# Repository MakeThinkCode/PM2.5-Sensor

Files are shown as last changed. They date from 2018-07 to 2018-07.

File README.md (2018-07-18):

# sensingtheenvpm25

Note for the web site:  the purpose of "sqlconnect-example.php" is to maintain privacy of the database access credentials; it should be copied to the web server, renamed to "sqlconnect.php", and then edited to contain the actual username etc.  The resulting sqlconnect.php should NOT then be included in the github source.

to do: docs, e.g. process for wiring, materials list (e.g. acrylic), process for editing the sensor code (setting the machine name), goals for installation, process for getting from the Fusion360 file to an assembled shelter, process for uploading data to the web site, calibration, setting up the web server (database, password file), next steps list, and so on.

Process for cutting the shelter from the 20180521 drawing:
1. Requires (from Home Depot, for instance) 3 sheets of 11x14 .093" thick acrylic per shelter.  (aside: The shelter design has slot widths designed for that thickness; you could change the "t" (thickness) parameter of the .f3d drawing and recompute and it SHOULD work, but no guarantees -- I've had problems adjusting .f3d parameters in the past.)
2. From the .f3d file, make a drawing (select visible components, D size sheet l:1 scale) of the parts, deleting the legend and border, precise layout not critical.
3.  Export the drawing into a PDF, since that's what Adobe Illustrator can read
4.  In Illustrator, change the line weight to .001pt and the line colors to red; also, right-click on the unwanted rectangular border, choose "release clipping mask", and then delete the border.
5.  In Illustrator, make 3 new drawings, 11x14, and distribute copies of the (eight) shelter components among the 3 drawings.  I ended up needing to make two changes to settings in the print dialog:  placement in the upper left corner and no auto-rotate.
6.  From Illustrator, do the laser cutting (print to the Trotec, and follow the normal instructions; I used 90% power and 0.70 speed with Auto PPI).

Assembling the shelter:
First, attach the Arduino and the Plantower to the centerboard with twist-ties through the holes.  Then slot together the outside and base of the shelter and drop in the centerboard with the sensor.  Put the lid in place and use two more twist-ties through the small top holes to hold the lid down, which is the step which latches everything together firmly.  Finally, slide the door into place.

Process for loading code onto the sensor:
Upload the code using the Arduino IDE.  One edit will be necessary for each sensor:  set the SENSOR_NAME in the code around line 40 (of code version 15, which is current as of July 2018). The name is included in the sensor output file and used for tagging the data in the database.  The name is also used in generating the file name for the sensor's data files (a new datafile is created every time the sensor is started:  a sensor named PARK will have data files named PARK_001.csv, PARK_002.csv, etc).  The second edit to remember is that any time the sensor code is modified, the SOFTWARE_VERSION should be changed; this will help separate out any data handling changes which need to be made in the server code and may be required for correct analysis of the data.
(need note here about setting up Arduino IDE, installing the Teensy loader, setting the "Port" to connect, using the console to check that the sensor is running properly, etc.)

Process for uploading data to the database, as of 7/2018:
1. Unplug the sensor from its power source.
2. Remove the micro-SD card from the Arduino.  On the micro-SD card will be files with names like PARK_001.csv, one for each time the sensor has been powered up.  You'll need to upload (one by one) any of these which haven't already been uploaded; you may want to copy them to your local computer for convenience.
3. Navigate a web browser to http://spatialreasoning.com/particulates and choose "Upload".
4.  On the upload page, first "browse" to find the .csv file from the sensor's micro-SD card, then "Upload PM2.5 Data" to actually do the upload.  This will take at least several seconds, with no immediate visual feedback; please be patient.
5.  When the upload finishes, the web page will display a graph of the readings, and will be ready to upload another file if you have multiple to upload.
6.  You likely will want to remove the .csv files from the micro-SD card to avoid future confusion about whether the files have been uploaded already.  If you do so, the next time the sensor is started up it will restart the data file numbering from 001.
7.  Replace the micro-SD card in the sensor.
8.  Plug the sensor in again.

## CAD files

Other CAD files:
shelter/lasercutting20180521/shelter20180521a v0.f3d
shelter/shelter2018-03.f3d

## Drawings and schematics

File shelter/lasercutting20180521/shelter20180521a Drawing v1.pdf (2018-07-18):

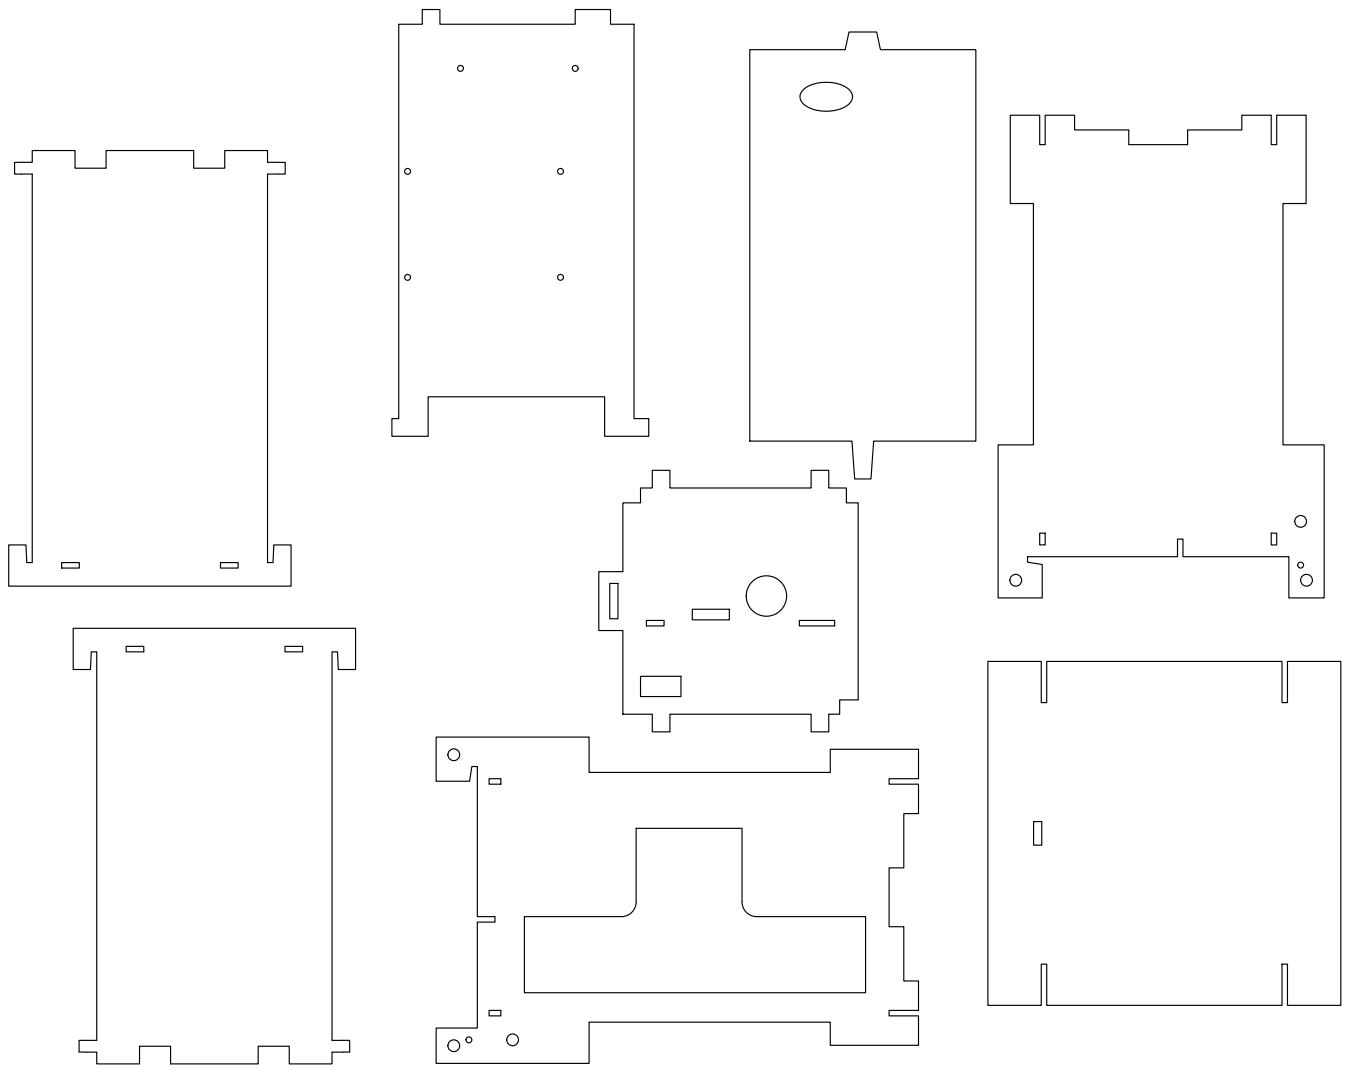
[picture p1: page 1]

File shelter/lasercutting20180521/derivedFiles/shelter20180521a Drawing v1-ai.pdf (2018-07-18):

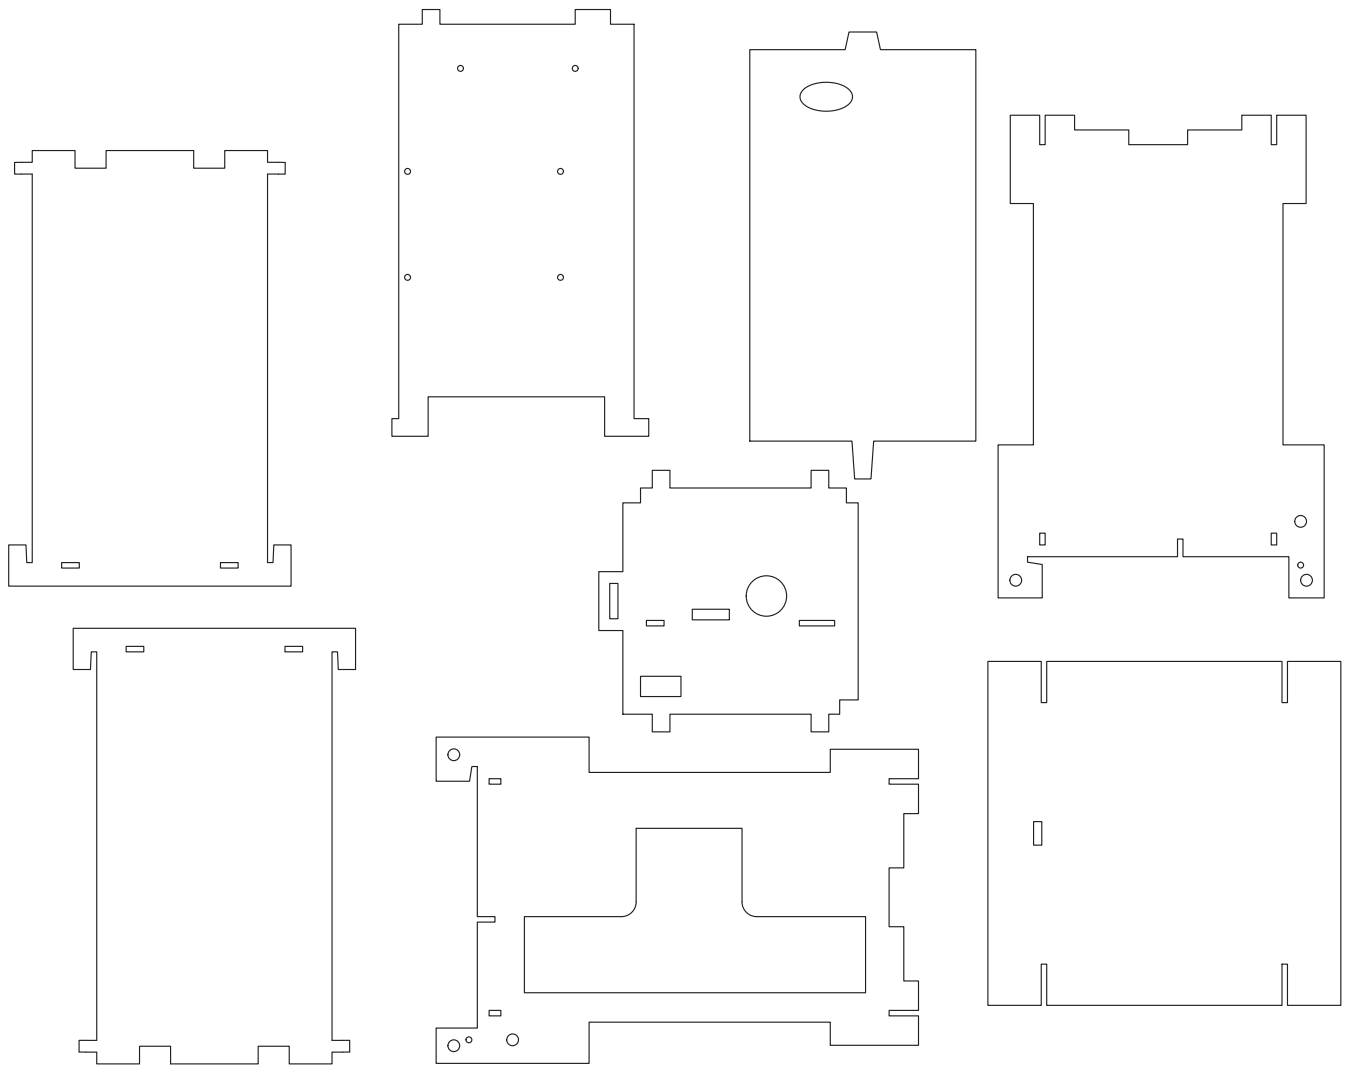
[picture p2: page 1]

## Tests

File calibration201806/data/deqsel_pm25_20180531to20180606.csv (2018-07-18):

PM2.5 Est[ug/m3(L)] Station: Portland SE Lafayette Periodically: 5/31/2018 12:05 AM-6/8/2018 12:00 AM Type: AVG 5 Mins. [5 Mins.]
Date & Time | PM2.5 Est
 | ug/m3(L)
5/31/2018 12:05 AM | 2.4
5/31/2018 12:10 AM | 2.2
5/31/2018 12:15 AM | 2.1
5/31/2018 12:20 AM | 2.1
5/31/2018 12:25 AM | 2.1
5/31/2018 12:30 AM | 2.0
5/31/2018 12:35 AM | 2.0
5/31/2018 12:40 AM | 2.0
5/31/2018 12:45 AM | 2.0
5/31/2018 12:50 AM | 2.0
5/31/2018 12:55 AM | 2.0
5/31/2018 1:00 AM | 2.0
5/31/2018 1:05 AM | 2.1
5/31/2018 1:10 AM | 2.1
5/31/2018 1:15 AM | 2.0
5/31/2018 1:20 AM | 2.0
5/31/2018 1:25 AM | 2.2
5/31/2018 1:30 AM | 2.1
5/31/2018 1:35 AM | 1.9
5/31/2018 1:40 AM | 2.1
5/31/2018 1:45 AM | 1.9
5/31/2018 1:50 AM | 2.0
5/31/2018 1:55 AM | 1.9
5/31/2018 2:00 AM | 1.8
5/31/2018 2:05 AM | 1.8
5/31/2018 2:10 AM | 1.9
5/31/2018 2:15 AM | 1.9
5/31/2018 2:20 AM | 1.9
5/31/2018 2:25 AM | 2.0
5/31/2018 2:30 AM | 2.0
5/31/2018 2:35 AM | 1.9
5/31/2018 2:40 AM | 1.9
5/31/2018 2:45 AM | 2.1
5/31/2018 2:50 AM | 2.1
5/31/2018 2:55 AM | 2.0
5/31/2018 3:00 AM | 2.0
5/31/2018 3:05 AM | 2.1
5/31/2018 3:10 AM | 2.3
5/31/2018 3:15 AM | 2.2
5/31/2018 3:20 AM | 2.2
5/31/2018 3:25 AM | 2.1
5/31/2018 3:30 AM | 2.2
5/31/2018 3:35 AM | 2.2
5/31/2018 3:40 AM | 2.3
5/31/2018 3:45 AM | 2.2
5/31/2018 3:50 AM | 2.2
5/31/2018 3:55 AM | 2.3
5/31/2018 4:00 AM | 2.5
5/31/2018 4:05 AM | 2.5
5/31/2018 4:10 AM | 2.8
5/31/2018 4:15 AM | 2.8
5/31/2018 4:20 AM | 2.9
5/31/2018 4:25 AM | 2.9
5/31/2018 4:30 AM | 2.8
5/31/2018 4:35 AM | 2.6
5/31/2018 4:40 AM | 2.7
5/31/2018 4:45 AM | 2.6
5/31/2018 4:50 AM | 2.1
5/31/2018 4:55 AM | 2.1
5/31/2018 5:00 AM | 2.1
5/31/2018 5:05 AM | 2.1
5/31/2018 5:10 AM | 2.3
5/31/2018 5:15 AM | 2.4
5/31/2018 5:20 AM | 2.7
5/31/2018 5:25 AM | 2.6
5/31/2018 5:30 AM | 2.6
5/31/2018 5:35 AM | 2.4
5/31/2018 5:40 AM | 2.3
5/31/2018 5:45 AM | 2.2
5/31/2018 5:50 AM | 2.1
5/31/2018 5:55 AM | zero
5/31/2018 6:00 AM | Calib
5/31/2018 6:05 AM | Purge
5/31/2018 6:10 AM | Purge
5/31/2018 6:15 AM | DL/Computer issue
5/31/2018 6:20 AM | 2.3
5/31/2018 6:25 AM | 2.4
5/31/2018 6:30 AM | 2.4
5/31/2018 6:35 AM | 2.4
5/31/2018 6:40 AM | 2.3
5/31/2018 6:45 AM | 2.3
5/31/2018 6:50 AM | 2.2
5/31/2018 6:55 AM | 2.5
5/31/2018 7:00 AM | 2.5
5/31/2018 7:05 AM | 2.7
5/31/2018 7:10 AM | 2.6
5/31/2018 7:15 AM | 2.4
5/31/2018 7:20 AM | 2.2
5/31/2018 7:25 AM | 2.2
5/31/2018 7:30 AM | 2.2
5/31/2018 7:35 AM | 2.3
5/31/2018 7:40 AM | 2.5
5/31/2018 7:45 AM | 2.4
5/31/2018 7:50 AM | 2.3
5/31/2018 7:55 AM | 2.2
5/31/2018 8:00 AM | 2.3
5/31/2018 8:05 AM | 2.4
5/31/2018 8:10 AM | 2.5
5/31/2018 8:15 AM | 2.6
5/31/2018 8:20 AM | 2.4
5/31/2018 8:25 AM | 2.6
5/31/2018 8:30 AM | 2.4
5/31/2018 8:35 AM | 2.7
5/31/2018 8:40 AM | 2.7
5/31/2018 8:45 AM | 2.7
5/31/2018 8:50 AM | 2.7
5/31/2018 8:55 AM | 2.6
5/31/2018 9:00 AM | 2.5
5/31/2018 9:05 AM | 2.3
5/31/2018 9:10 AM | 2.3
5/31/2018 9:15 AM | 2.2
5/31/2018 9:20 AM | 2.2
5/31/2018 9:25 AM | 2.1
5/31/2018 9:30 AM | 2.3
5/31/2018 9:35 AM | 2.3
5/31/2018 9:40 AM | 2.2
5/31/2018 9:45 AM | 2.1
5/31/2018 9:50 AM | 2.1
5/31/2018 9:55 AM | 2.1
5/31/2018 10:00 AM | 2.2
5/31/2018 10:05 AM | 2.2
5/31/2018 10:10 AM | 2.0
5/31/2018 10:15 AM | 1.8
5/31/2018 10:20 AM | 2.0
5/31/2018 10:25 AM | 1.8
5/31/2018 10:30 AM | 1.8
5/31/2018 10:35 AM | 1.9
5/31/2018 10:40 AM | 1.9
5/31/2018 10:45 AM | 1.7
5/31/2018 10:50 AM | 1.9
5/31/2018 10:55 AM | 2.0
5/31/2018 11:00 AM | 1.9
5/31/2018 11:05 AM | 2.0
5/31/2018 11:10 AM | 2.0
5/31/2018 11:15 AM | 1.8
5/31/2018 11:20 AM | 2.0
5/31/2018 11:25 AM | 2.0
5/31/2018 11:30 AM | 1.9
5/31/2018 11:35 AM | 1.9
5/31/2018 11:40 AM | 1.9
5/31/2018 11:45 AM | 1.9
5/31/2018 11:50 AM | 2.0
5/31/2018 11:55 AM | 2.1
5/31/2018 12:00 PM | 2.4
5/31/2018 12:05 PM | 2.2
5/31/2018 12:10 PM | 2.3
5/31/2018 12:15 PM | 2.2
5/31/2018 12:20 PM | 2.3
5/31/2018 12:25 PM | 2.4
5/31/2018 12:30 PM | 2.3
5/31/2018 12:35 PM | 2.4
5/31/2018 12:40 PM | 2.6
5/31/2018 12:45 PM | 2.5
5/31/2018 12:50 PM | 2.7
5/31/2018 12:55 PM | 2.6
5/31/2018 1:00 PM | 2.8
5/31/2018 1:05 PM | 2.9
5/31/2018 1:10 PM | 3.0
5/31/2018 1:15 PM | 2.9
5/31/2018 1:20 PM | 3.0
5/31/2018 1:25 PM | 3.0
5/31/2018 1:30 PM | 2.7
5/31/2018 1:35 PM | 2.4
5/31/2018 1:40 PM | 2.7
5/31/2018 1:45 PM | 3.0
5/31/2018 1:50 PM | 3.2
5/31/2018 1:55 PM | 3.2
5/31/2018 2:00 PM | 3.2
5/31/2018 2:05 PM | 3.1
5/31/2018 2:10 PM | 3.0
5/31/2018 2:15 PM | 3.1
5/31/2018 2:20 PM | 3.0
5/31/2018 2:25 PM | 3.2
5/31/2018 2:30 PM | 3.4
5/31/2018 2:35 PM | 3.4
5/31/2018 2:40 PM | 3.6
5/31/2018 2:45 PM | 3.5
5/31/2018 2:50 PM | 3.0
5/31/2018 2:55 PM | 2.6
5/31/2018 3:00 PM | 2.8
5/31/2018 3:05 PM | 2.4
5/31/2018 3:10 PM | 2.3
5/31/2018 3:15 PM | 2.0
5/31/2018 3:20 PM | 2.1
5/31/2018 3:25 PM | 2.1
5/31/2018 3:30 PM | 2.2
5/31/2018 3:35 PM | 2.6
5/31/2018 3:40 PM | 2.7
5/31/2018 3:45 PM | 2.6
5/31/2018 3:50 PM | 2.5
5/31/2018 3:55 PM | 2.3
5/31/2018 4:00 PM | 2.3
5/31/2018 4:05 PM | 2.4
5/31/2018 4:10 PM | 3.0
5/31/2018 4:15 PM | 2.7
5/31/2018 4:20 PM | 2.9
5/31/2018 4:25 PM | 2.8
5/31/2018 4:30 PM | 2.6
5/31/2018 4:35 PM | 2.0
5/31/2018 4:40 PM | 2.2
5/31/2018 4:45 PM | 1.9
5/31/2018 4:50 PM | 1.9
5/31/2018 4:55 PM | 2.0
5/31/2018 5:00 PM | 1.8
5/31/2018 5:05 PM | 2.1
5/31/2018 5:10 PM | 2.5
5/31/2018 5:15 PM | 2.4
5/31/2018 5:20 PM | 2.5
5/31/2018 5:25 PM | 2.4
5/31/2018 5:30 PM | 2.5
5/31/2018 5:35 PM | 2.3
5/31/2018 5:40 PM | 2.5
5/31/2018 5:45 PM | 2.2
5/31/2018 5:50 PM | 2.3
5/31/2018 5:55 PM | 2.1
5/31/2018 6:00 PM | 2.3
5/31/2018 6:05 PM | 2.3
5/31/2018 6:10 PM | 2.4
5/31/2018 6:15 PM | 2.3
5/31/2018 6:20 PM | 2.2
5/31/2018 6:25 PM | 2.5
5/31/2018 6:30 PM | 2.4
5/31/2018 6:35 PM | 2.3
5/31/2018 6:40 PM | 1.8
5/31/2018 6:45 PM | 2.4
5/31/2018 6:50 PM | 3.8
5/31/2018 6:55 PM | 3.5
5/31/2018 7:00 PM | 3.1
5/31/2018 7:05 PM | 3.2
5/31/2018 7:10 PM | 3.1
5/31/2018 7:15 PM | 3.7
5/31/2018 7:20 PM | 3.6
5/31/2018 7:25 PM | 2.4
5/31/2018 7:30 PM | 2.1
5/31/2018 7:35 PM | 2.0
5/31/2018 7:40 PM | 2.3
5/31/2018 7:45 PM | 2.7
5/31/2018 7:50 PM | 2.8
5/31/2018 7:55 PM | 2.9
5/31/2018 8:00 PM | 3.0
5/31/2018 8:05 PM | 2.9
5/31/2018 8:10 PM | 2.9
5/31/2018 8:15 PM | 3.0
5/31/2018 8:20 PM | 3.1
5/31/2018 8:25 PM | 2.9
5/31/2018 8:30 PM | 2.8
5/31/2018 8:35 PM | 2.9
5/31/2018 8:40 PM | 2.9
5/31/2018 8:45 PM | 3.0
5/31/2018 8:50 PM | 3.2
5/31/2018 8:55 PM | 3.0
5/31/2018 9:00 PM | 2.8
5/31/2018 9:05 PM | 2.7
5/31/2018 9:10 PM | 2.8
5/31/2018 9:15 PM | 3.1
5/31/2018 9:20 PM | 3.1
5/31/2018 9:25 PM | 3.3
5/31/2018 9:30 PM | 3.2
5/31/2018 9:35 PM | 3.6
5/31/2018 9:40 PM | 4.0
5/31/2018 9:45 PM | 3.9
5/31/2018 9:50 PM | 4.3
5/31/2018 9:55 PM | 4.2
5/31/2018 10:00 PM | 4.1
5/31/2018 10:05 PM | 4.0
5/31/2018 10:10 PM | 4.2
5/31/2018 10:15 PM | 4.5
5/31/2018 10:20 PM | 4.9
5/31/2018 10:25 PM | 5.0
5/31/2018 10:30 PM | 5.4
5/31/2018 10:35 PM | 5.5
5/31/2018 10:40 PM | 5.0
5/31/2018 10:45 PM | 4.3
5/31/2018 10:50 PM | 3.9
5/31/2018 10:55 PM | 3.4
5/31/2018 11:00 PM | 3.6
5/31/2018 11:05 PM | 3.6
5/31/2018 11:10 PM | 3.6
5/31/2018 11:15 PM | 3.8
5/31/2018 11:20 PM | 4.0
5/31/2018 11:25 PM | 4.6
5/31/2018 11:30 PM | 5.1
5/31/2018 11:35 PM | 4.9
5/31/2018 11:40 PM | 3.9
5/31/2018 11:45 PM | 3.4
5/31/2018 11:50 PM | 3.4
5/31/2018 11:55 PM | 3.2
5/31/2018 24:00 AM | 3.0
6/1/2018 12:05 AM | 2.9
6/1/2018 12:10 AM | 3.6
6/1/2018 12:15 AM | 3.6
6/1/2018 12:20 AM | 3.4
6/1/2018 12:25 AM | 3.5
6/1/2018 12:30 AM | 3.3
6/1/2018 12:35 AM | 3.3
6/1/2018 12:40 AM | 3.4
6/1/2018 12:45 AM | 3.6
6/1/2018 12:50 AM | 4.1
6/1/2018 12:55 AM | 3.7
6/1/2018 1:00 AM | 3.6
6/1/2018 1:05 AM | 3.7
6/1/2018 1:10 AM | 3.6
6/1/2018 1:15 AM | 3.4
6/1/2018 1:20 AM | 3.6
6/1/2018 1:25 AM | 4.6
6/1/2018 1:30 AM | 4.5
6/1/2018 1:35 AM | 4.4
6/1/2018 1:40 AM | 4.1
6/1/2018 1:45 AM | 4.1
6/1/2018 1:50 AM | 4.1
6/1/2018 1:55 AM | 4.1
6/1/2018 2:00 AM | 3.8
6/1/2018 2:05 AM | 3.9
6/1/2018 2:10 AM | 3.8
6/1/2018 2:15 AM | 3.7
6/1/2018 2:20 AM | 3.8
6/1/2018 2:25 AM | 3.9
6/1/2018 2:30 AM | 4.0
6/1/2018 2:35 AM | 4.1
6/1/2018 2:40 AM | 4.0
6/1/2018 2:45 AM | 3.8
6/1/2018 2:50 AM | 3.8
6/1/2018 2:55 AM | 3.6
6/1/2018 3:00 AM | 3.4
6/1/2018 3:05 AM | 3.6
6/1/2018 3:10 AM | 3.5
6/1/2018 3:15 AM | 3.3
6/1/2018 3:20 AM | 3.1
6/1/2018 3:25 AM | 3.1
6/1/2018 3:30 AM | 3.1
6/1/2018 3:35 AM | 3.2
6/1/2018 3:40 AM | 3.1
6/1/2018 3:45 AM | 3.2
6/1/2018 3:50 AM | 3.3
6/1/2018 3:55 AM | 3.4
6/1/2018 4:00 AM | 3.2
6/1/2018 4:05 AM | 3.5
6/1/2018 4:10 AM | 3.9
6/1/2018 4:15 AM | 3.6
6/1/2018 4:20 AM | 3.9
6/1/2018 4:25 AM | 3.9
6/1/2018 4:30 AM | 3.7
6/1/2018 4:35 AM | 3.9
6/1/2018 4:40 AM | 3.7
6/1/2018 4:45 AM | 3.6
6/1/2018 4:50 AM | 3.7
6/1/2018 4:55 AM | 3.5
6/1/2018 5:00 AM | 3.4
6/1/2018 5:05 AM | 3.3
6/1/2018 5:10 AM | 3.3
6/1/2018 5:15 AM | 3.1
6/1/2018 5:20 AM | 3.1
6/1/2018 5:25 AM | 3.2
6/1/2018 5:30 AM | 3.2
6/1/2018 5:35 AM | 3.2
6/1/2018 5:40 AM | 3.3
6/1/2018 5:45 AM | 3.3
6/1/2018 5:50 AM | 3.2
6/1/2018 5:55 AM | zero
6/1/2018 6:00 AM | Calib
6/1/2018 6:05 AM | Purge
6/1/2018 6:10 AM | Purge
6/1/2018 6:15 AM | DL/Computer issue
6/1/2018 6:20 AM | 3.5
6/1/2018 6:25 AM | 3.5
6/1/2018 6:30 AM | 3.5
6/1/2018 6:35 AM | 3.7
6/1/2018 6:40 AM | 4.0
6/1/2018 6:45 AM | 3.8
6/1/2018 6:50 AM | 3.5
6/1/2018 6:55 AM | 3.4
6/1/2018 7:00 AM | 3.3
6/1/2018 7:05 AM | 3.1
6/1/2018 7:10 AM | 3.2
6/1/2018 7:15 AM | 3.0
6/1/2018 7:20 AM | 3.3
6/1/2018 7:25 AM | 4.0
6/1/2018 7:30 AM | 4.0
6/1/2018 7:35 AM | 3.9
6/1/2018 7:40 AM | 3.9
6/1/2018 7:45 AM | 3.3
6/1/2018 7:50 AM | 3.1
6/1/2018 7:55 AM | 3.1
6/1/2018 8:00 AM | 2.8
6/1/2018 8:05 AM | 2.7
6/1/2018 8:10 AM | 2.8
6/1/2018 8:15 AM | 2.5
6/1/2018 8:20 AM | 2.5
6/1/2018 8:25 AM | 2.6
6/1/2018 8:30 AM | 2.6
6/1/2018 8:35 AM | 2.5
6/1/2018 8:40 AM | 2.4
6/1/2018 8:45 AM | 2.4
6/1/2018 8:50 AM | 2.3
6/1/2018 8:55 AM | 1.9
6/1/2018 9:00 AM | 2.1
6/1/2018 9:05 AM | 1.9
6/1/2018 9:10 AM | 2.0
6/1/2018 9:15 AM | 2.0
6/1/2018 9:20 AM | 1.9
6/1/2018 9:25 AM | 2.0
6/1/2018 9:30 AM | 1.9
6/1/2018 9:35 AM | 1.9
6/1/2018 9:40 AM | 1.7
6/1/2018 9:45 AM | 1.7
6/1/2018 9:50 AM | 1.6
6/1/2018 9:55 AM | 1.7
6/1/2018 10:00 AM | 1.7
6/1/2018 10:05 AM | 1.7
6/1/2018 10:10 AM | 1.6
6/1/2018 10:15 AM | 1.7
6/1/2018 10:20 AM | 2.0
6/1/2018 10:25 AM | 2.1
6/1/2018 10:30 AM | 1.7
6/1/2018 10:35 AM | 1.5
6/1/2018 10:40 AM | 1.6
6/1/2018 10:45 AM | 1.6
6/1/2018 10:50 AM | 1.8
6/1/2018 10:55 AM | 1.8
6/1/2018 11:00 AM | 1.6
6/1/2018 11:05 AM | 1.8
6/1/2018 11:10 AM | 1.7
6/1/2018 11:15 AM | 1.7
6/1/2018 11:20 AM | 1.7
6/1/2018 11:25 AM | 1.6
6/1/2018 11:30 AM | 1.7
6/1/2018 11:35 AM | 1.8
6/1/2018 11:40 AM | 1.9
6/1/2018 11:45 AM | 2.0
6/1/2018 11:50 AM | 1.8
6/1/2018 11:55 AM | 2.0
6/1/2018 12:00 PM | 2.1
6/1/2018 12:05 PM | 2.0
6/1/2018 12:10 PM | 2.1
6/1/2018 12:15 PM | 2.1
6/1/2018 12:20 PM | 2.1
6/1/2018 12:25 PM | 2.2
6/1/2018 12:30 PM | 2.2
6/1/2018 12:35 PM | 2.2
6/1/2018 12:40 PM | 2.2
6/1/2018 12:45 PM | 2.3
6/1/2018 12:50 PM | 2.3
6/1/2018 12:55 PM | 2.3
6/1/2018 1:00 PM | 2.5
6/1/2018 1:05 PM | 2.5
6/1/2018 1:10 PM | 2.5
6/1/2018 1:15 PM | 2.4
6/1/2018 1:20 PM | 2.5
6/1/2018 1:25 PM | 2.5
6/1/2018 1:30 PM | 2.5
6/1/2018 1:35 PM | 2.4
6/1/2018 1:40 PM | 2.5
6/1/2018 1:45 PM | 2.6
6/1/2018 1:50 PM | 2.7
6/1/2018 1:55 PM | 2.6
6/1/2018 2:00 PM | 2.8
6/1/2018 2:05 PM | 2.8
6/1/2018 2:10 PM | 2.7
6/1/2018 2:15 PM | 2.8
6/1/2018 2:20 PM | 2.7
6/1/2018 2:25 PM | 2.8
6/1/2018 2:30 PM | 2.8
6/1/2018 2:35 PM | 2.6
6/1/2018 2:40 PM | 2.7
6/1/2018 2:45 PM | 2.7
6/1/2018 2:50 PM | 2.7
6/1/2018 2:55 PM | 2.9
6/1/2018 3:00 PM | 2.9
6/1/2018 3:05 PM | 2.9
6/1/2018 3:10 PM | 2.7
6/1/2018 3:15 PM | 2.5
6/1/2018 3:20 PM | 2.6
6/1/2018 3:25 PM | 2.4
6/1/2018 3:30 PM | 2.6
6/1/2018 3:35 PM | 2.6
6/1/2018 3:40 PM | 2.6
6/1/2018 3:45 PM | 2.7
6/1/2018 3:50 PM | 2.6
6/1/2018 3:55 PM | 2.7
6/1/2018 4:00 PM | 2.6
6/1/2018 4:05 PM | 2.7
6/1/2018 4:10 PM | 2.7
6/1/2018 4:15 PM | 2.6
6/1/2018 4:20 PM | 2.8
6/1/2018 4:25 PM | 2.8
6/1/2018 4:30 PM | 2.7
6/1/2018 4:35 PM | 2.7
6/1/2018 4:40 PM | 2.9
6/1/2018 4:45 PM | 2.7
6/1/2018 4:50 PM | 2.8
6/1/2018 4:55 PM | 2.9
6/1/2018 5:00 PM | 2.8
6/1/2018 5:05 PM | 2.8
6/1/2018 5:10 PM | 2.9
6/1/2018 5:15 PM | 2.8
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

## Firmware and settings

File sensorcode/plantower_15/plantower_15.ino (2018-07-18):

/*
 * version 14 was used for the calibration run at DEQ in June 2018.
 * changes for version 15:
 *  - time/date stamp on file
 *  - report 1-minute averages in the file (rather than the current reading every 2 seconds)
 the output file name format should be
 AAAA_000.csv -- the name can be alphanum and not necessarily just 4 chars, so
 underscore for the separator from the numbers
  TO DO:
  - display page
  - multi-file upload
  - save file after uploading
  - file name format to match between this and data upload page
*/
 
 
 
 
 
 
 
 //******************************
 //*Abstract: Read value of PM1,PM2.5 and PM10 of air quality
 //
 //*Version：V3.1
 //*Author：Zuyang @ HUST
 //*Modified by Cain for Arduino Hardware Serial port compatibility
 //*Date：March.25.2016
 //* further modified by Bennett Battaile, Philip Orlando, Meenakshi Rao
 //*  for real-time clock, SD card saving, using Teensy board, etc.,
 //*  beginning 7/2017
 //******************************
#include <Arduino.h>
#include <SD.h>
#include <SPI.h>
#include <Wire.h>
#include <TimeLib.h>
#include <DS1307RTC.h>


#define SENSOR_NAME      "ROBB"  //  up to 4 characters used for file name; file name is AAC_003.CSV
#define FNAME_USED_CHARS 4
#define FILE_SUFFIX      ".CSV" // must be upper case!
#define SOFTWARE_VERSION "15"
#define DELETE_OTHER_CSV_FILES 1
#define COLS_HDR "date-time, millis, status, navg, PM1.0std ug/m3,  PM2.5std ug/m3,  PM10std ug/m3, " \
                 "PM1.0atm ug/m3,  PM2.5atm ug/m3,  PM10atm ug/m3, " \
                 "pcnt/dl .3um, pcnt/dl .5um,  pcnt/dl 1um, pcnt/dl 2.5um, pcnt/dl 5um, pcnt/dl 10um"
#define NEW_LOGFILE_EVERY_TIME 1  // whether each restart begins a new logfile or reuses the same one

#define LENG 31   //0x42 + 31 bytes equal to 32 bytes
unsigned char buf[LENG];
int bufIndex = -1;
const int chipSelect = 10;
  
// plantower code adapted from
//  https://www.dfrobot.com/wiki/index.php/PM2.5_laser_dust_sensor_SKU:SEN0177
int PM01Value=0;          //define PM1.0 value of the air detector module
int PM2_5Value=0;         //define PM2.5 value of the air detector module
int PM10Value=0;         //define PM10 value of the air detector module


// each buffer full of readings from the sensor goes into latestDataSet.
int latestDataSet[12];

// latestDataSet is added in to an accumulator for doing 1-minute averaging.
int numAccumulatedDataSets;
int accumulatedDataSets[12];
String datadatetime = "0000-00-00 00:00:00"; // time of latest data point
int currentMinute; // for doing 1-minute averaging



String datalogfilename; // limited to 8.3 filename


// from Blink example code:
// Pin 13 has an LED connected on most Arduino boards.
// Pin 11 has the LED on Teensy 2.0
// Pin 6  has the LED on Teensy++ 2.0
// Pin 13 has the LED on Teensy 3.0
// give it a name:
int led = 13;

// use these directly as number of blinks and as status for log file
int blink_allfine = 1;
int blink_error2 = 2;
int blink_error3 = 3;
int blink_error4 = 4;
int blink_error5 = 5;
int blink_error6 = 6;
int maxnumblinks = 6;
int blinkstatus = blink_allfine;
unsigned long enteredthisblinkstatewhen;
unsigned long nextchangeblinkwhen;

String sensornameprefix()
{
  String answer(SENSOR_NAME);
  answer = answer.substring(0,FNAME_USED_CHARS);
  return answer;
}


// call back for file timestamps - https://forum.arduino.cc/index.php?topic=348562.0
void dateTimeCB(uint16_t* date, uint16_t* tim)
{
  tmElements_t tm;  
  if (RTC.read(tm)) {
    *date = FAT_DATE(tmYearToCalendar(tm.Year), tm.Month, tm.Day);
    *tim  = FAT_TIME(tm.Hour, tm.Minute, tm.Second);
  }  
}



void setup()
{
  // from Blink example code:
  // initialize the digital pin as an output.
  pinMode(led, OUTPUT);

  //initialize serial ports
  Serial.begin(9600);   //use serial0
  Serial.setTimeout(1500);    //set the Timeout to 1500ms, longer than the data transmission periodic time of the sensor

  //added the Serial1 lines -mr 2017-08-18
  Serial1.begin(9600);         //use serial0
  Serial1.setTimeout(1500);    //set the Timeout to 1500ms, longer than the data transmission periodic time of the sensor

  //digitalWrite(10,HIGH); // BB this was thought for a while to help with SD card initialization problems, but maybe not.  7/17

  if (Serial) Serial.println(String("plantower_") + SOFTWARE_VERSION);

  initblinkstate();

  //lines through Serial.println("card initialized") from Teensy Datalogger example  BB 7/17
  //BB 7/17 if(Serial) in case usb isn't plugged in; if(Serial1) is always true per https://www.arduino.cc/en/Serial/IfSerial
  //to initialize the SD card, which is on the Teensy Audio board,
  //chipSelect should be set to 10
  if (Serial) Serial.print("Initializing SD card... ");
  //UNCOMMENT THESE TWO LINES FOR TEENSY AUDIO BOARD:
  SPI.setMOSI(7);  // Audio shield has MOSI on pin 7
  SPI.setSCK(14);  // Audio shield has SCK on pin 14

  // see if the card is present and can be initialized:
  if (!SD.begin(chipSelect)) {
    if (Serial) Serial.println("Card failed, or not present");
    // don't do anything more:
    return;
  }  
  if (Serial) Serial.println("card initialized.");

  cleanoutirrelevantfiles();
  makedatalogfilename();


  
  //dumpDataFile(); // handy to be able to see the file without pulling the card out

  String hdr1 = String("monitor starting up,")
                     + "name=" + SENSOR_NAME
                     + ", swversion=" + SOFTWARE_VERSION
                     + ", datetime=" + getdatetime() + "";
  String hdr2 = COLS_HDR;
  
  SdFile::dateTimeCallback(dateTimeCB); // https://forum.arduino.cc/index.php?topic=348562.0

  File dataFile = SD.open(datalogfilename.c_str(), FILE_WRITE);
  if (dataFile) {
    dataFile.println(hdr1);
    dataFile.println(hdr2);
    dataFile.close(); // to be reopened for every data write
  } else {
    Serial.println("could not write header to data file");  // unlikely error
  }
  Serial.println(hdr1);
  Serial.println(hdr2);
}


//  delete any .csv files which aren't from this sensor, to reduce confusion
//  if the card was used in a different monitor
void cleanoutirrelevantfiles()
{
  if ( !DELETE_OTHER_CSV_FILES )
    return;
    
  File root;
  root = SD.open("/");
  while (true) {
    File entry =  root.openNextFile();
    if (! entry) {
      // no more files
      break;
    }
    if ( String(entry.name()).startsWith(sensornameprefix()) ) {
      Serial.println( String("keeping ") + entry.name());
    } else if ( String(entry.name()).endsWith(FILE_SUFFIX) ) {
      Serial.println( String("deleting file: ") + entry.name());
      String fullpath = String("/")+entry.name();
      SD.remove(fullpath.c_str());      
    } else {
      Serial.println( String("ignoring ") + entry.name());      
    }
    entry.close();
  }
  root.close();
}


// format:  SENSOR_NAME + _ + 4-digit number + FILE_SUFFIX
// we'll go through all such, extract the numbers, and
// return a new name with the next higher number so as
// to not collide with existing.
void makedatalogfilename()
{
  if ( ! NEW_LOGFILE_EVERY_TIME )
  {
    // we'll reuse the same log file
    datalogfilename = String(sensornameprefix()) + "_001" + String(FILE_SUFFIX);
    Serial.println( String("output file name:  " ) + datalogfilename);
    return;
  }
  Serial.println("figuring out next data file name");
  int highwater = 0; // highest number seen (so we'll start by generating 00001)
  File root;
  root = SD.open("/");
  while (true) {
    File entry =  root.openNextFile();
    if (! entry) {
      // no more files
      break;
    }
    if ( String(entry.name()).startsWith(sensornameprefix()+"_") 
      && String(entry.name()).endsWith(FILE_SUFFIX) ) {
      Serial.println( String("considering ") + entry.name());
      String mycopy = entry.name();
      mycopy.replace(sensornameprefix()+"_", "");
      mycopy.replace(FILE_SUFFIX, "");
      // now it should be a pure number.
      int seen = mycopy.toInt();
      if ( seen > highwater )
      {
        highwater = seen;
      }
    } else {
      Serial.println( String("ignoring ") + entry.name());      
    }
    entry.close();
  }
  root.close();
  char tmpbuf[55];
  sprintf(tmpbuf, "%03d", highwater+1);
  datalogfilename = String(sensornameprefix()) + "_" + String(tmpbuf) + String(FILE_SUFFIX);
  Serial.println( String("output file name:  " ) + datalogfilename);
}





void serialEvent1() {
    int b = 0;

    // when not already started a message, flush everything up to first 'B'
    while (bufIndex < 0 && (b = Serial1.read()) >= 0 && b != 'B');

    // if we got a start byte start a new message
    if ('B' == b) bufIndex = 0;

    // fill all available bytes into open message buffer
    while (0 <= bufIndex && bufIndex < sizeof(buf) && Serial1.available())
    {
        buf[bufIndex++] = Serial1.read();
    }

    if (bufIndex == sizeof(buf))
    {
        if(buf[0] == 0x4d && checkValue(buf,LENG))
        {
            fillLatestDataSet();
            //PM01Value=transmitPM01(buf); //count PM1.0 value of the air detector module
            //PM2_5Value=transmitPM2_5(buf);//count PM2.5 value of the air detector module
            //PM10Value=transmitPM10(buf); //count PM10 value of the air detector module
            //Serial.println("data updated"); // happens about 1x/sec
        }
        bufIndex = -1;  // mark as treated and ready for next message
    }
    //Serial.println("serialEvent1 called " + String(bufIndex) + " " + String(buf[0]));
}

void fillLatestDataSet()
{
    if ( isItANewMinute() ) 
    {
        writeDataToLogFile();
        clearDataAccumulator();
    }
    datadatetime = getdatetime();
    for ( int i = 0; i < 12; i++ ) 
    {
        int hi = buf[2*i+3];
        int lo = buf[2*i+4];
        latestDataSet[i] = (hi<<8) + lo;
    }

  String dataString =  " ";
  for ( int i = 0; i < 12; i++ )
  {
    dataString += String(latestDataSet[i]);
    if ( i+1 < 12 )
      dataString += ", ";
  }
  Serial.println("** - " + dataString);
  
    
    
    addToDataAccumulator();
}

int isItANewMinute()
{
    tmElements_t tm;
    if (RTC.read(tm))
    {
        if ( tm.Minute != currentMinute )
        {
            currentMinute = tm.Minute;
            return 1;
        }
    }
    return 0;
}

void clearDataAccumulator()
{
    numAccumulatedDataSets = 0;
    for ( int i = 0; i < 12; i++ ) 
    {
        accumulatedDataSets[i] = 0;
    }
}

void addToDataAccumulator()
{
    numAccumulatedDataSets ++;
    for ( int i = 0; i < 12; i++ ) 
    {
        accumulatedDataSets[i]  += latestDataSet[i];
    }
}

String reportDataAccumulator()
{
    String answer  =  "";

    answer += String(numAccumulatedDataSets) + ", ";
  
    for ( int i = 0; i < 12; i++ )
    {
        float avg = (numAccumulatedDataSets < 1)
                  ? 0
                  : ((float)accumulatedDataSets[i]/(float)numAccumulatedDataSets);
        answer += String(avg,3);  // how many decimal places?  Say 3.
        if ( i+1 < 12 )
            answer += ", ";
    }
    return answer;
}


// 2-second activity cycle
void loop()
{
  static unsigned long OldTimer=millis();

  if ( bufIndex != -1 ) return;

  unsigned long timenow = millis();
  if ( timenow > nextchangeblinkwhen ) {
        transitionblink();
  }
  if ( timenow - OldTimer < 2000 ) {
    asm volatile("wfi"); // Magic from Paul.
    return;
  }
  OldTimer=timenow; 

//  writeDataToLogFile();  do this in the serialEvent function instead
}



void writeDataToLogFile()
{
  String dataString = "";
  /*
  dataString =  " ";
  for ( int i = 0; i < 12; i++ )
  {
    dataString += String(latestDataSet[i]);
    if ( i+1 < 12 )
      dataString += ", ";
  }
  */
  dataString = reportDataAccumulator();

  String dateTime = datadatetime; // want the last data point time, not now (which will be later)

  // open the file. note that only one file can be open at a time,
  // so you have to close this one before opening another.
  File dataFile = SD.open(datalogfilename.c_str(), FILE_WRITE);
  if ( !dataFile ) {
    // see if we can shake things into place by reading the file  instead of writing
    File tmp = SD.open(datalogfilename.c_str(), FILE_READ);
    if ( tmp ) tmp.close();
    
    if ( SD.begin(chipSelect) ) {  // desperation: reinitialize SD connection
      dataFile = SD.open(datalogfilename.c_str(), FILE_WRITE);
      if ( dataFile ) {
        blinkstatus = blink_error4;  // open succeeded but only after SD re-init
      } else {
        blinkstatus = blink_error5;  // reinitialized SD, still couldn't open file
      }
    } else {
      blinkstatus = blink_error6;  // couldn't open file and couldn't reinitialize SD
    }
  }

  // if the file is available, write to it:
  String toprint = dateTime + ", " + millis() + ", " + blinkstatus + ", " + dataString;
  if (dataFile) {
    dataFile.println(toprint);
    dataFile.close();
  }
  if(Serial) Serial.println(toprint);
  
  
}




String getdatetime()
{
  String dateTime = "0000-0-0 00:00:00"; // overwritten unless RTC fails
  tmElements_t tm;

  if (RTC.read(tm)) {
    dateTime = String(tmYearToCalendar(tm.Year)) + "-" + 
               String(tm.Month) + "-" +
               String(tm.Day) + " " +
               as2digits(tm.Hour) + ":" +
               as2digits(tm.Minute) + ":" +
               as2digits(tm.Second);
  } else {
    if (RTC.chipPresent()) {
      blinkstatus = blink_error2;   // bad data from RTC
      if ( Serial ) {
        Serial.println("The DS1307 is stopped.  Please run the SetTime");
        Serial.println("example to initialize the time and begin running.");
        Serial.println();
      }
    } else {
      blinkstatus = blink_error3;  // no RTC -- low voltage can cause this
      if (Serial) {
        Serial.println("DS1307 read error!  Please check the circuitry.  (low voltage?)");
        Serial.println();
      }
    }
  }
  
  return dateTime;
}


char checkValue(unsigned char *thebuf, char leng)
{
  char receiveflag=0;
  int receiveSum=0;

  for(int i=0; i<(leng-2); i++){
    receiveSum=receiveSum+thebuf[i];
  }
  receiveSum=receiveSum + 0x42;

  if(receiveSum == ((thebuf[leng-2]<<8)+thebuf[leng-1]))  //check the serial data
  {
    receiveSum = 0;
    receiveflag = 1;
  }
  return receiveflag;
}

int transmitPM01(unsigned char *thebuf)
{
  int PM01Val;
  PM01Val=((thebuf[3]<<8) + thebuf[4]); //count PM1.0 value of the air detector module
  return PM01Val;
}

//transmit PM Value to PC
int transmitPM2_5(unsigned char *thebuf)
{
  int PM2_5Val;
  PM2_5Val=((thebuf[5]<<8) + thebuf[6]);//count PM2.5 value of the air detector module
  return PM2_5Val;
}

//transmit PM Value to PC
int transmitPM10(unsigned char *thebuf)
{
  int PM10Val;
  PM10Val=((thebuf[7]<<8) + thebuf[8]); //count PM10 value of the air detector module
  return PM10Val;
}

void print2digits(int number) {
  if (number >= 0 && number < 10) {
    Serial.write('0');
  }
  Serial.print(number);
}

String as2digits(int number) {
  String answer = "";
  if (number >= 0 && number < 10) {
    answer += ('0');
  }
  answer += String(number);
  return(answer);
}



//int numblinkstoshow;

int currentblinknumber; // on-off are same number
int ison;  // to differentiate states within a blink number
int onduration = 200;
int offduration = 200;
int pauseduration = 400; // = onduration+offduration is nice
//int currentstate; // 

void initblinkstate() {

    enteredthisblinkstatewhen = millis();
    digitalWrite(led, HIGH);
    currentblinknumber = 1;
    ison = 1;
    setnextblinkchange();
}

void setnextblinkchange() {
    if ( currentblinknumber == blinkstatus && !ison ) {
        // the off after the blink merges with the between-cycle pause
        nextchangeblinkwhen = enteredthisblinkstatewhen + offduration + pauseduration;
    } else if ( ison ) {
        nextchangeblinkwhen = enteredthisblinkstatewhen + onduration;
    } else  { // !ison
        nextchangeblinkwhen = enteredthisblinkstatewhen + offduration;
    }
}


void transitionblink() {
    enteredthisblinkstatewhen = millis();
    if ( ison ) {
        digitalWrite(led, LOW);
    } else {
        digitalWrite(led, HIGH);
    }
    ison  = !ison;
    if ( ison) {
        currentblinknumber ++;
        if ( currentblinknumber > blinkstatus ) {
            currentblinknumber = 1;
        }
    }
    setnextblinkchange();
}





void dumpDataFile()
{
  String filetodump("datalog.txt");
  File myFile = SD.open(filetodump.c_str(), FILE_READ);
  if (myFile) {
    // from https://www.arduino.cc/en/Tutorial/ReadWrite
    Serial.println(filetodump + " contains:");

    // read from the file until there's nothing else in it:
    while (myFile.available()) {
      Serial.write(myFile.read());
    }
    // close the file:
    myFile.close();
    Serial.println("---- end  -----");
  } else {
    Serial.println(filetodump + ": couldn't open data file");
  }
}

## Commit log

2018-03-20 initial state for sensor, shelter, and web page
    [shelter2018-03.f3d]
2018-07-18 upload: sw version 15, web page, calibration info
    [deqsel_pm25_20180531to20180606.csv, shelter20180521a v0.f3d]
2018-07-23 beginning of popup graph for sensors on display page
2018-08-17 add sw_version.php for updating sensor version
